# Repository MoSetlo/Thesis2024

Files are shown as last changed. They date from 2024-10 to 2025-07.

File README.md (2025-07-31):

# Thesis2024

##### Report - https://drive.google.com/drive/folders/1f2lx2jlqezw4tI6jubJ7p_Oo5HgsuzDn?usp=sharing

The purpose of this study is to design and implement a lightweight control system and remote
interface to convert a commercially available helium balloon into a fully functional blimp. This
research aims to explore how custom-designed hardware and software can transform an ordinary
inflatable structure into a maneuverable LTA vehicle, The study seeks to address key challenges
in stability, control precision, and propulsion by developing a custom motor driver, optimizing
PID-based stabilization, and minimizing latency issues using a custom-built remote controller.

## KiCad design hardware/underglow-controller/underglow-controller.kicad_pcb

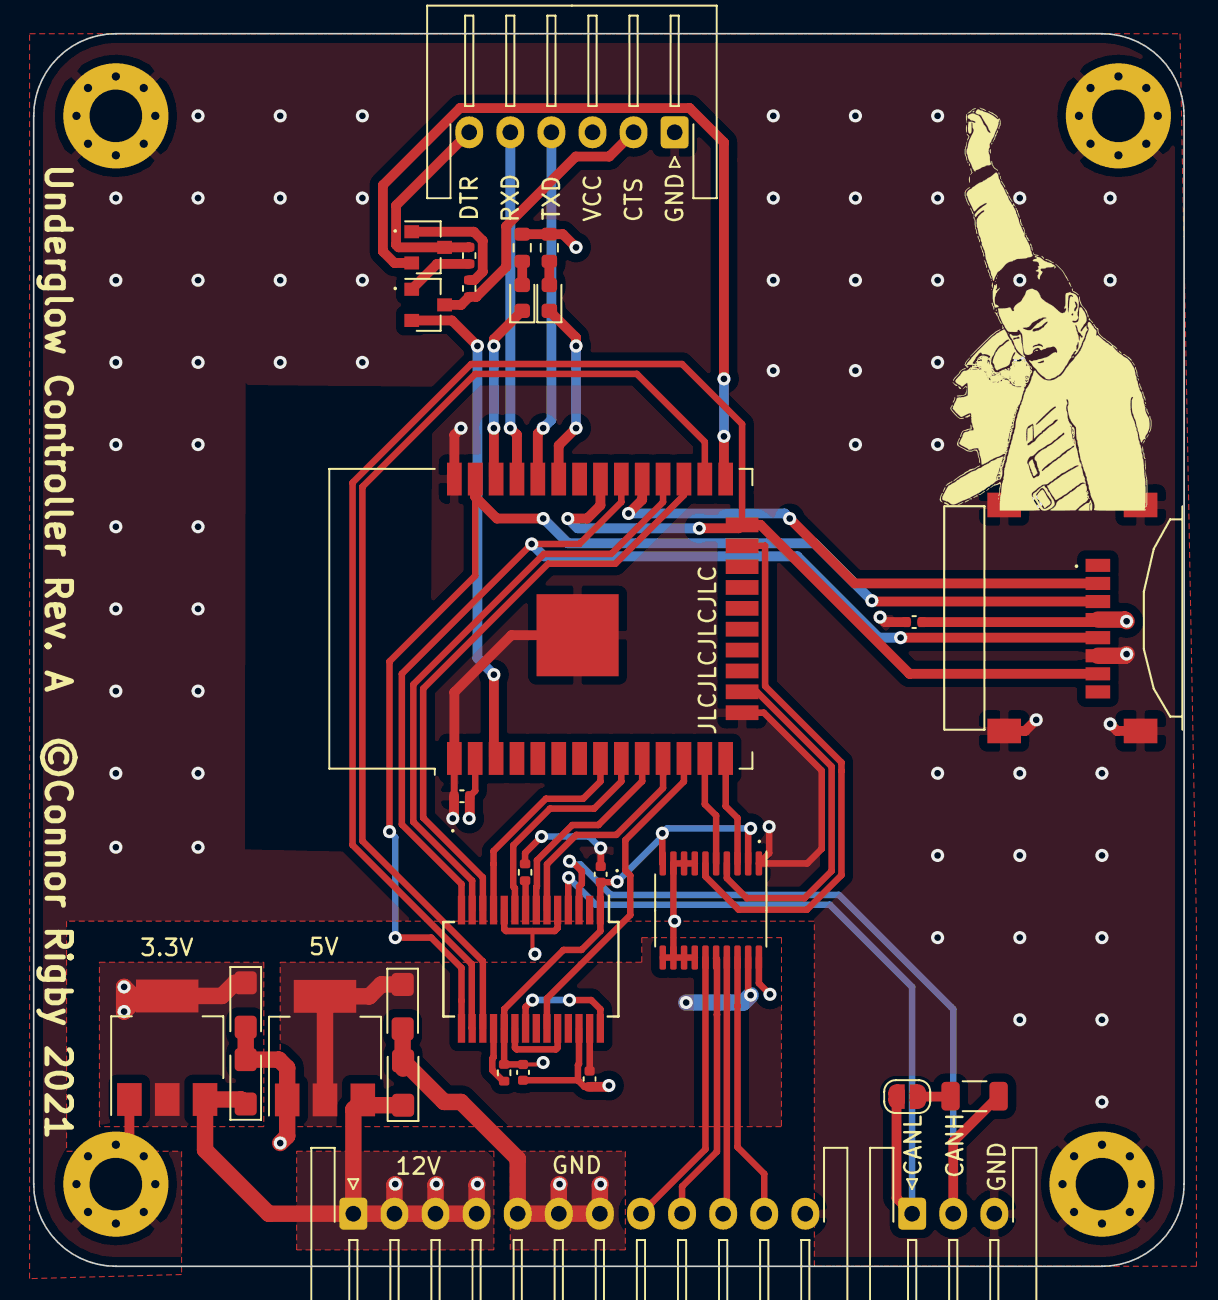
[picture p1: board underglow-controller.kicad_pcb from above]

Board: 4 copper layers, 70.0 x 75.0 mm, 34 parts (0 on the bottom side), 43 nets.

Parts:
C1, C2, C3, C4: 10u; CP_EIA-3216-18_Kemet-A
C5, C6, C7, C8, C9: 100n; C_0402_1005Metric
D1, D2: LED_Small; LED_0603_1608Metric
H1, H2, H3, H4: MountingHole_Pad; MountingHole_3.2mm_M3_Pad_Via
J1: Micro_SD_Card; MOLEX_47219-2001
J2: FTDI; JST_XH_S6B-XH-A-1_1x06_P2.50mm_Horizontal
J3: LEDS; JST_XH_S12B-XH-A-1_1x12_P2.50mm_Horizontal
J4: CAN; JST_XH_S3B-XH-A-1_1x03_P2.50mm_Horizontal
JP1: Jumper_NO_Small; SolderJumper-2_P1.3mm_Open_RoundedPad1.0x1.5mm
Q1, Q2: SS8050; SOT-23
R1, R2, R5, R6: 10k; R_0402_1005Metric
R3, R4: R_Small; R_0603_1608Metric
R7: 120; R_1206_3216Metric
U1: AMS1117-3.3; SOT-223-3_TabPin2
U2: TXS0108EPW; TSSOP-20_4.4x6.5mm_P0.65mm
U3: AMS1117-5.0; SOT-223-3_TabPin2
U4: ESP32-WROOM-32D; ESP32-WROOM-32
U5: MCP25625-x-SS; SSOP-28_5.3x10.2mm_P0.65mm

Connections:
+3V3: C2.1, C5.2, C6.2, C7.2, C8.2, J1.4, R3.1, R4.1, R5.2, U1.2, U2.2, U2.10, U4.2, U5.1, U5.19
+5V: C4.1, C9.2, U2.19, U3.2, U5.27
+12V: C1.1, C3.1, J3.1, J3.2, J3.3, J3.4, U1.3, U3.3
/CANH: J4.1, JP1.1, U5.4
/CANL: J4.2, R7.2, U5.3
/CAN_INT: U4.28, U5.13
/CAN_RX0_BF: U4.27, U5.12
/CAN_RX1_BF: U4.8, U5.11
/CAN_TX0_RTS: U4.12, U5.23
/CAN_TX1_RTS: U4.11, U5.6
/CAN_TX2_RTS: U4.10, U5.7
/FTDI_CTS: J2.2, Q1.3, R2.2
/FTDI_DTR: J2.6, Q2.3, R1.2
/FTDI_RX: J2.5, U4.35
/FTDI_TX: J2.4, U4.34
/GPIO0: Q2.2, U4.25
/LED0: U2.4, U4.16
/LED0_OUT: J3.10, U2.17
/LED1: U2.3, U4.14
/LED1_OUT: J3.11, U2.18
/LED2: U2.5, U4.13
/LED2_OUT: J3.9, U2.16
/LED3: U2.6, U4.23
/LED3_OUT: J3.8, U2.15
/RESET: Q1.2, U4.3
/SD_CLK: J1.5, U4.30, U5.14
/SD_CMD: J1.3, U4.37, U5.15
/SD_D0: J1.7, U4.24, U4.31, U5.16
/SD_D3: J1.2, U4.29
/SPI_CS: U4.26, U5.17
/STATUS0: D1.1, U4.33
/STATUS1: D2.1, U4.36
/XTAL_OUT: U4.9, U5.9
GND: C1.2, C2.2, C3.2, C4.2, C5.1, C6.1, C7.1, C8.1, C9.1, H1.1, H2.1, H3.1, H4.1, J1.6, J1.G1, J1.G2, J1.G3, J1.G4, J2.1, J3.5, J3.6, J3.7, J3.12, J4.3, R6.2, U1.1, U2.1, U2.7, U2.8, U2.9, U2.11, U2.12, U2.13, U2.14, U2.20, U3.1, U4.1, U4.15, U4.38, U4.39, U5.5, U5.10, U5.26
unnamed: D1.2, R3.2
unnamed: D2.2, R4.2
unnamed: JP1.2, R7.1
unnamed: Q1.1, R1.1
unnamed: Q2.1, R2.1
unnamed: R5.1, U5.18
unnamed: R6.1, U5.8
unnamed: U5.20, U5.24
unnamed: U5.21, U5.28

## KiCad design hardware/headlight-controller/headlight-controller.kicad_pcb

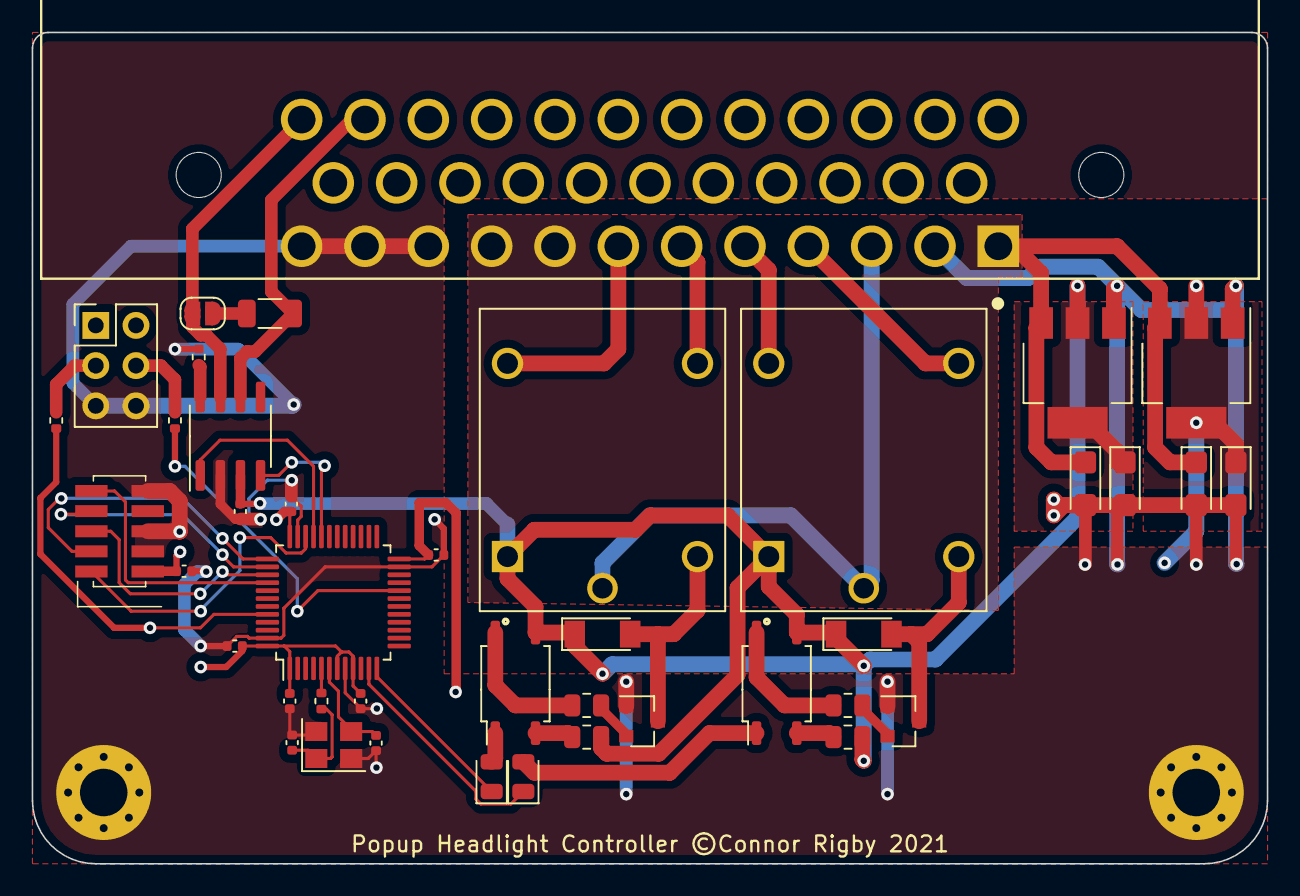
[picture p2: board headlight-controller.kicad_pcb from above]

Board: 2 copper layers, 78.0 x 52.5 mm, 43 parts (0 on the bottom side), 39 nets.

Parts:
C1, C2, C3, C7: 10u; CP_EIA-3216-18_Kemet-A
C4, C6: 12p; C_0402_1005Metric
C5, C8, C9, C10, C11, C12, C13: 100n; C_0402_1005Metric
D1, D2: RED; LED_0805_2012Metric
D3, D4: ZMM5V6; D_MiniMELF
H1, H2: MountingHole_Pad; MountingHole_3mm_Pad_Via
J1: Conn_ARM_JTAG_SWD_10; 20021221-00010C4LF
J2: 776180-1; TE_776180-1
J3: BOOT; PinHeader_2x03_P2.54mm_Vertical
JP1: Jumper_NO_Small; SolderJumper-2_P1.3mm_Open_RoundedPad1.0x1.5mm
K1, K2: SRD-05VDC-SL-C; RELAY_SRD-05VDC-SL-C
Q1, Q2: S8050; SOT-23
R1, R2: 1k; R_0805_2012Metric
R3, R4: 510; R_0805_2012Metric
R5: 120; R_1206_3216Metric
R6, R8: 100K; R_0402_1005Metric
R7: 1M; R_0402_1005Metric
R9: 4.7k; R_0402_1005Metric
U1: AMS1117-3.3; SOT-223-3_TabPin2
U2: AMS1117-5.0; SOT-223-3_TabPin2
U3: STM32F103C8Tx; LQFP-48_7x7mm_P0.5mm
U4: MCP2551-I-SN; SOIC-8_3.9x4.9mm_P1.27mm
U5, U6: EL357N(B)(TA)-G; SOP-4_4.1x4.4mm_P2.54mm
Y1: Crystal_GND24_Small; Crystal_SMD_3225-4Pin_3.2x2.5mm

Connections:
+3V3: C2.1, C5.1, C8.1, C9.1, C10.1, C11.1, C12.1, J1.1, J3.1, J3.2, U1.2, U3.1, U3.7, U3.9, U3.24, U3.36, U3.48
+5V: C7.1, C13.1, D3.1, D4.1, K1.A1, K2.A1, R1.2, R2.2, U2.2, U4.3, U5.3, U6.3
+12V: C1.1, C3.1, J2.1, J2.8, J2.9, U1.3, U2.3
/BOOT0: R6.2, U3.44
/BOOT1: R8.1, U3.20
/CANH: J2.35, JP1.1, U4.7
/CANL: J2.34, R5.1, U4.6
/CAN_RX: U3.32, U4.4
/CAN_TX: U3.33, U4.1
/HL1_DN: J2.7, K1.NC
/HL1_IN: D1.1, U3.12
/HL1_UP: J2.6, K1.NO
/HL2_DN: J2.5, K2.NC
/HL2_IN: D2.1, U3.11
/HL2_UP: J2.4, K2.NO
/HL_COM: J2.3, K1.COM, K2.COM
/HSE_IN: R7.1, U3.5
/HSE_OUT: C6.1, U3.6, Y1.3
/JNTRST: J1.10, U3.40
/SWDCLK: J1.4, U3.37
/SWDIO: J1.2, U3.34
/SWO: J1.6, U3.39
/TDI: J1.8, U3.38
GND: C1.2, C2.2, C3.2, C4.2, C5.2, C6.2, C7.2, C8.2, C9.2, C10.2, C11.2, C12.2, C13.2, H1.1, H2.1, J1.3, J1.5, J1.9, J2.2, J2.10, J2.11, J2.12, J3.5, J3.6, Q1.1, Q2.1, R9.1, U1.1, U2.1, U3.8, U3.23, U3.35, U3.47, U4.2, Y1.2, Y1.4
unnamed: C4.1, R7.2, Y1.1
unnamed: D1.2, U5.1
unnamed: D2.2, U6.1
unnamed: D3.2, K1.A2, Q1.3
unnamed: D4.2, K2.A2, Q2.3
unnamed: J3.3, R6.1
unnamed: J3.4, R8.2
unnamed: JP1.2, R5.2
unnamed: Q1.2, R3.1
unnamed: Q2.2, R4.1
unnamed: R1.1, U5.2
unnamed: R2.1, U6.2
unnamed: R3.2, U5.4
unnamed: R4.2, U6.4
unnamed: R9.2, U4.8

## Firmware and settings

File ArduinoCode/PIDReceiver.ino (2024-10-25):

#include <esp_now.h> //esp-idf
#include <WiFi.h>
#include <Adafruit_MPU6050.h>
#include <Adafruit_Sensor.h>



#define CHANNEL 6 //Must Match Slave
#define FRONT_MOTOR_PIN 12
#define BACK_MOTOR_PIN 2
#define LEFT_MOTOR_PIN 13
#define RIGHT_MOTOR_PIN 3
#define BattADCPin 5
#define FREQUENCY 40000
#define PWM_RESOLUTION 8
#define MPU_SDA 16
#define MPU_SCL 18

/** This is all the data about the peer **/
esp_now_peer_info_t slave;  //MacAdress of Receiver
uint8_t broadcastAddress[] = {0xCC,0x8D,0xA2,0x88, 0x63, 0x4A}; //CC:8D:A2:88:63:4A
esp_err_t result;



/** The all important data**/
uint8_t dataSend = 0; //Should be 250 bytes or less - can be int, struct. Struct could be useful or partition xy adc values

typedef struct joystick{ //struct to hold xy values of two joysticks from transmitter
  uint16_t xL, yL, xR, yR=500; uint8_t leftStickClick =1; 
  float Pyaw,Ppitch,Iyaw,Ipitch,Dyaw,Dpitch=0;
};
joystick joyStk;
joystick* newJoyStk = &joyStk;

typedef struct dataLog{

int_fast8_t frontMotor=0;
int_fast8_t backMotor=0;
int_fast8_t leftMotor=0;
int_fast8_t rightMotor=0;
float RateRoll, RateYaw=0;
float PitchAngle=0;
float battStatus=0;
int recLoop=0;
float Pyaw,Ppitch,Iyaw,Ipitch,Dyaw,Dpitch=0;
};

dataLog recData;


/**Global Variables**/
int_fast8_t frontMotor;
int_fast8_t backMotor;
int_fast8_t leftMotor;
int_fast8_t rightMotor;
int_fast8_t yawStick;
int_fast8_t throttleLeftStick;
int_fast8_t pitchStick;
int_fast8_t throttleRightStick; //int incase of negative signage

//BatteryVoltage============================
float battVoltage;
uint8_t batteryLow;

//IMU Gyro===================================
Adafruit_MPU6050 mpu;

float RateRoll, RatePitch, RateYaw;
float RateRollCalib, RatePitchCalib, RateYawCalib;
int RateCalibNum;
float AccelX, AccelY, AccelZ;
float AnglePitchCalib,AnglePitch=0;
int Looptimer;

//PID Terms====================================
float Pyaw,Ppitch,Iyaw,Ipitch,Dyaw,Dpitch;
float ErrorYaw,ErrorPitchRate,ErrorPitchAngle,PrevErrorYaw,PrevErrorPitchRate,PrevErrorPitchAngle,PrevItermYaw,PrevItermPitch,PrevItermPitchAngle;
float DesiredYawRate, DesiredPitchAngle;
float PIDInputYaw,PIDInputPitch=0;

float PIDReturnIterm;
//Other

uint8_t startLoop=0;



void gyro_rates()
{

/* Get new sensor events with the readings */
  sensors_event_t a, g, temp;
  mpu.getEvent(&a, &g, &temp);

  RatePitch = g.gyro.y * 57.2958;

  RateRoll = g.gyro.x * 57.2958;

  RateYaw = g.gyro.z * 57.2958;

  AccelX = a.acceleration.x/9.80665;

  AccelY = a.acceleration.y/9.80665;

  AccelZ = a.acceleration.z/9.80665;


}

float PIDcontroller(float Pconst, float Iconst, float Dconst, float Error, float PrevError, float PrevIterm,float MaxOut)
{
  float Pterm = Pconst*Error;
  float Iterm = PrevIterm + (Iconst*(Error+PrevError)*0.005/2);
  float Dterm = Dconst*(Error-PrevError)/0.005;

  //AntiWindup

  if(Iterm>MaxOut){
    Iterm=MaxOut;
  }
  else if(Iterm<-MaxOut)
  {
    Iterm=-MaxOut;
  }

  float PIDout= Pterm+Iterm+Dterm;

  if(PIDout>MaxOut){
    PIDout=MaxOut;
  }
  else if(PIDout<-MaxOut)
  {
    PIDout=-MaxOut;
  }

  //PIDReturn[0] = Error;
  PIDReturnIterm = Iterm;

  return PIDout;

}







void setup(){
//blade spin stop
  pinMode(FRONT_MOTOR_PIN, OUTPUT);  // Set as output
  digitalWrite(FRONT_MOTOR_PIN, LOW); // Ensure it's off at boot
pinMode(BACK_MOTOR_PIN, OUTPUT);  // Set as output
  digitalWrite(BACK_MOTOR_PIN, LOW); // Ensure it's off at boot
  pinMode(LEFT_MOTOR_PIN, OUTPUT);  // Set as output
  digitalWrite(LEFT_MOTOR_PIN, LOW); // Ensure it's off at boot
  pinMode(RIGHT_MOTOR_PIN, OUTPUT);  // Set as output
  digitalWrite(RIGHT_MOTOR_PIN, LOW); // Ensure it's off at boot


  /*ESPNow Setup====================================*/
  Serial.begin(115200); //Serial com
  delay(1000);
  WiFi.mode(WIFI_STA);  //Set mode to station mode
  WiFi.setChannel(CHANNEL);
  
  if (esp_now_init() != ESP_OK) { //initialises espnow protocol
    Serial.println("Error initializing ESP-NOW");
    return;
  }

  esp_now_register_send_cb(OnDataSent); //send callback on delivery
  esp_now_register_recv_cb(OnDataRecv); //send callback on reception

  memcpy(slave.peer_addr, broadcastAddress, 6); //copy broadcast address memory into slave object
  slave.channel = CHANNEL; 
  slave.encrypt =0;
  esp_now_add_peer(&slave);


  /*MPU SETUP*/
  while (!mpu.begin()) {
    Serial.println("Failed to find MPU6050 chip");
  }


  mpu.setAccelerometerRange(MPU6050_RANGE_8_G);
 
  mpu.setGyroRange(MPU6050_RANGE_500_DEG); //therefore in degrees per seconds

  mpu.setFilterBandwidth(MPU6050_BAND_10_HZ);


  pinMode(15, OUTPUT);
  digitalWrite(15, HIGH);

  delay(1000);

//beginning gyro calibration
  // digitalWrite(15, LOW);
  // delay(1000);

  // digitalWrite(15, HIGH);
  // delay(1000);

  // digitalWrite(15, LOW);


  // for(RateCalibNum =0 ; RateCalibNum<2000; RateCalibNum++)
  // {
  //   gyro_rates();
  //   RateRollCalib+=RateRoll;
  //   RatePitchCalib+=RatePitch;
  //   RateYawCalib += RateYaw;
  //   AnglePitchCalib=0.98*(AnglePitchCalib+(RatePitch*0.005)) + 0.02*(atan(-AccelX/sqrt(AccelY*AccelY + AccelZ*AccelZ)) * 57.2958);
  //   delay(1);
  // }
  
  // RateRollCalib/=2000;
  // RatePitchCalib/=2000;
  // RateYawCalib/=2000;

  // Serial.println("Calibration Complete");
  // digitalWrite(15, HIGH);
  // delay(1000);

  /*Joystick Setup===================================*/
  frontMotor,backMotor, leftMotor, rightMotor, yawStick, throttleLeftStick, pitchStick, throttleRightStick = 0;

  /*PWM SETUP===============================*/
  ledcAttach(FRONT_MOTOR_PIN, FREQUENCY, PWM_RESOLUTION);
  ledcWrite(FRONT_MOTOR_PIN, 0);

  ledcAttach(BACK_MOTOR_PIN, FREQUENCY, PWM_RESOLUTION);
  ledcWrite(BACK_MOTOR_PIN, 0);
  

  ledcAttach(LEFT_MOTOR_PIN, FREQUENCY, PWM_RESOLUTION);
  ledcWrite(LEFT_MOTOR_PIN, 0);

  ledcAttach(RIGHT_MOTOR_PIN, FREQUENCY, PWM_RESOLUTION);
  ledcWrite(RIGHT_MOTOR_PIN, 0);



  //ADC Battery Check
  analogReadResolution(10);
  batteryLow=0;

  //PID Setup variables
  PrevErrorYaw,PrevErrorPitchAngle,PrevItermYaw,PrevItermPitchAngle=0;

  Pyaw=(newJoyStk->Pyaw);
  Iyaw=(newJoyStk->Iyaw);
  Dyaw=(newJoyStk->Dyaw);

  Ppitch=(newJoyStk->Ppitch);
  Ipitch=(newJoyStk->Ipitch);
  Dpitch=(newJoyStk->Dpitch);

  //PIDReturn[0]=0;
  PIDReturnIterm=0;

  delay(3000);
  digitalWrite(15, LOW);
}

void loop(){
  //Remote control Lock 

  if(!newJoyStk->leftStickClick && newJoyStk->yR >850){
    startLoop=0; //Loop paused

    ledcWrite(FRONT_MOTOR_PIN, 0);
    ledcWrite(BACK_MOTOR_PIN, 0);
    ledcWrite(LEFT_MOTOR_PIN, 0 );
    ledcWrite(RIGHT_MOTOR_PIN, 0);

    PrevErrorYaw,PrevErrorPitchAngle,PrevItermYaw,PrevItermPitchAngle=0;
    digitalWrite(15, LOW);

    delay(3000);

  }

  while(!startLoop) //loop paused
  {

    Serial.println("Waiting for Stick Click");
    if(!newJoyStk->leftStickClick && newJoyStk->yR >550)
    {
      startLoop=1;
      digitalWrite(15, HIGH);
  
  delay(1000);

  digitalWrite(15, LOW);
  delay(1000);

  digitalWrite(15, HIGH);
  delay(1000);

  digitalWrite(15, LOW);


  for(RateCalibNum =0 ; RateCalibNum<2000; RateCalibNum++)
  {
    gyro_rates();
    RateRollCalib+=RateRoll;
    RatePitchCalib+=RatePitch;
    RateYawCalib += RateYaw;
    AnglePitchCalib=0.98*(AnglePitchCalib+(RatePitch*0.005)) + 0.02*(atan(-AccelX/sqrt(AccelY*AccelY + AccelZ*AccelZ)) * 57.2958);
    delay(1);
  }
  
  RateRollCalib/=2000;
  RatePitchCalib/=2000;
  RateYawCalib/=2000;

  Serial.println("Calibration Complete");
  digitalWrite(15, HIGH);
  delay(2000);

    }
    delay(3000);
    //calll reset errror
  }

  //Loop Timer
  Looptimer = micros();

  /*Battery Voltage Check*/
  //=============================================================
  battVoltage = (float)analogRead(BattADCPin)/205+0.3; //1024 to 5V mapp

  if(battVoltage<3.45) //assumption one would need to restart system
  {
    //batteryLow=1;
    digitalWrite(15, LOW);
    // dataSend = 1;

    // /*ESP_Now*/
    // result =  esp_now_send(slave.peer_addr, &dataSend, sizeof(dataSend)); // sends data to slave
  }
  else //assumption one would need to restart system
  {
    //batteryLow=0;
    digitalWrite(15, HIGH);
    // dataSend = 1;

    // /*ESP_Now*/
    // result =  esp_now_send(slave.peer_addr, &dataSend, sizeof(dataSend)); // sends data to slave
  }

  /*JoyStick PWM DUTY Mapping====================*/
  //====================================================
  if(newJoyStk->yL >470)  //Throttle input left joystick from joystick middle (forward propulsion) 
  {
    throttleLeftStick=0;
  }

  else if(newJoyStk->yL <=470)
  {
    throttleLeftStick = map(newJoyStk->yL, 470, 0, 0, 85); //maximum 60% speed Note int8
    
  }

  //============================================
  // Throttle input right joystick from joystick middle(lift)

  if(newJoyStk->yR>=550)
  {
    throttleRightStick=0; //10% hover
  }

  else if(newJoyStk->yR>470 && newJoyStk->xL <550)
  {
    throttleRightStick= 0; //1% hover, just to show it works
  }

  else if(newJoyStk->yR<=470)
  {
    throttleRightStick = map(newJoyStk->yR,470,0,2,125); //maximum 60% lift speed hover 
  }

  //=====================================================
  if(newJoyStk->xL <=470) //Right yaw
  {
    yawStick = map(newJoyStk->xL, 470,0,0,-150); //maximum 20% might change for no massive pwm
  }

  else if(newJoyStk->xL >=550) //Left yaw
  {
    yawStick = map(newJoyStk->xL, 550,1023,0,+150);
  }


  else if(newJoyStk->xL >470 && newJoyStk->xL <550 )
  {
    yawStick = 0;
  }

//MPU======================================
  //Looptimer = micros();
  gyro_rates();
  RateRoll-=RateRollCalib;
  RatePitch -= RatePitchCalib;
  RateYaw -= RateYawCalib;
  AnglePitch=0.98*(AnglePitch+(RatePitch*0.005)) + 0.02*((atan(-AccelX/sqrt(AccelY*AccelY + AccelZ*AccelZ)) * 57.2958)-AnglePitchCalib);

// additional
Pyaw=60
  Iyaw=9

  Ppitch=0.3
  Dpitch=5
//
  

  DesiredYawRate = 0.12*(yawStick);
  ErrorYaw= DesiredYawRate-RateYaw;

  DesiredPitchAngle=0;
  ErrorPitchAngle = DesiredPitchAngle-AnglePitch;


  PIDInputYaw = PIDcontroller(Pyaw, Iyaw, Dyaw, ErrorYaw, PrevErrorYaw, PrevItermYaw,150);
  PrevErrorYaw = ErrorYaw;
  PrevItermYaw = PIDReturnIterm;


  PIDInputPitch = PIDcontroller(Ppitch, Ipitch, Dpitch, ErrorPitchAngle, PrevErrorPitchAngle, PrevItermPitchAngle, 50);
  PrevErrorPitchAngle = ErrorPitchAngle;
  PrevItermPitchAngle = PIDReturnIterm;


  leftMotor = throttleLeftStick - PIDInputYaw;
  rightMotor = throttleLeftStick + PIDInputYaw;
  frontMotor = throttleRightStick - PIDInputPitch;
  backMotor = throttleRightStick + PIDInputPitch;

  if(leftMotor<0)
  {
    leftMotor=0;
  }
  if(rightMotor<0)
  {
    rightMotor=0;
  }
  if(frontMotor<0)
  {
    frontMotor=0;
  }
  if(backMotor<0)
  {
    backMotor=0;
  }

  if(leftMotor>250)
  {
    leftMotor=250;
  }
  if(rightMotor>250)
  {
    rightMotor=250;
  }
  if(frontMotor>250)
  {
    frontMotor=250;
  }
  if(backMotor>250)
  {
    backMotor=250;
  }




  ledcWrite(FRONT_MOTOR_PIN, frontMotor);
  ledcWrite(BACK_MOTOR_PIN, backMotor);
  ledcWrite(LEFT_MOTOR_PIN, leftMotor );
  ledcWrite(RIGHT_MOTOR_PIN, rightMotor);

  recData.frontMotor = frontMotor;
  recData.backMotor = backMotor;
  recData.leftMotor = leftMotor;
  recData.rightMotor = rightMotor;
  recData.PitchAngle = AnglePitch;
  recData.RateYaw = RateYaw;
  recData.RateRoll = RateRoll;
  recData.battStatus = battVoltage;
  recData.recLoop = micros()-Looptimer;
  recData.Ppitch = Ppitch;
  recData.Pyaw = Pyaw;
  recData.Ipitch = Ipitch;
  recData.Iyaw = Iyaw;
  recData.Dpitch = Dpitch;
  recData.Dyaw = Dyaw;
  

  result =  esp_now_send(slave.peer_addr, (uint8_t*)&recData, sizeof(recData)); // sends data to slave


  


  //Serial.printf("%d \t %d \t %.2f \t %d \t %d \t %.2f \t %.2f \t %d \t %.2f\n", frontMotor,backMotor,AnglePitch,leftMotor, rightMotor,RateYaw, RateRoll, micros()-Looptimer ,battVoltage);
  while(micros()-Looptimer < 5000);
  

}


void OnDataSent(const uint8_t *mac_addr, esp_now_send_status_t status) //callback, expectation for 0 output
{
  // Serial.print("Data status ->");
  // Serial.println(status);
}

void OnDataRecv(const esp_now_recv_info_t * esp_now_info, const uint8_t *data, int data_len) //callback on reception
{
  newJoyStk = (joystick*) data;
  // Serial.print("Data received by ->");
  // Serial.println(*data);
  // memcpy(&newData, data, sizeof(newData));

}

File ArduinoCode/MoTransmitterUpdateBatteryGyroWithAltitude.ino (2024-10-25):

#include <esp_now.h> //esp-idf
#include <WiFi.h>
#include <esp_timer.h>

#define CHANNEL 6 //Must Match Slave
#define X_Left 5
#define Y_Left 3
#define X_Right 9
#define Y_Right 7
#define altitudeHoldBtn 12



/** This is all the data about the peer **/
esp_now_peer_info_t slave;  //MacAdress of Receiver
uint8_t broadcastAddress[] = {0xCC,0x8D,0xA2,0x8B, 0xFF, 0x7A};
esp_err_t result;



/** The all important data! **/
//uint8_t data = 0; //Should be 250 bytes or less - can be int, struct. Struct could be useful or partition xy adc values
typedef struct joystick{ //struct to hold xy values of two joysticks
  uint16_t xL, yL, xR, yR=500; uint8_t leftStickClick=1; 
  float Pyaw,Ppitch,Iyaw,Ipitch,Dyaw,Dpitch=0;
};
joystick joyStk;

typedef struct dataLog{

int_fast8_t frontMotor=0;
int_fast8_t backMotor=0;
int_fast8_t leftMotor=0;
int_fast8_t rightMotor=0;
float RateRoll, RateYaw=0;
float PitchAngle=0;
float battStatus=4;
int recLoop=0;
float Pyaw,Ppitch,Iyaw,Ipitch,Dyaw,Dpitch=0;

};

dataLog recData;
dataLog *newRecData = &recData;


uint8_t startLoop=0;

//dataReceice
uint8_t dataReceive=0;


/**Packet timer rate**/
uint_fast8_t counter=0;
uint_fast64_t start=0;
uint_fast64_t end = 0;

//Others
String PIDsym;
float PIDval;
int LoopTimer=0;

//ExternalInterrupt
uint8_t altHoldStatus=0;
int_fast8_t externalCounter=0;
int_fast8_t altHoldVal=512;
uint32_t debounceTimer=0;


// void IRAM_ATTR altitudeHold()
// {

  
//   if(!altHoldStatus)
//   {
//     altHoldStatus=1;
//     altHoldVal= analogRead(X_Right); 
//     digitalWrite(39,HIGH);
//     externalCounter=0;
//   }
//   else if(altHoldStatus && altHoldVal>470)
//   {
//     altHoldStatus=0;
//     digitalWrite(39,LOW);

//   }



//}

void setup(){
  /*ESP_Now setup*/
  Serial.begin(115200); //Serial com
  delay(1000);
  WiFi.mode(WIFI_STA);  //Set mode to station mode
  WiFi.setChannel(CHANNEL);

  if (esp_now_init() != ESP_OK) { //initialises espnow protocol
    Serial.println("Error initializing ESP-NOW");
    return;
}

  esp_now_register_send_cb(OnDataSent); //send callback on delivery
  esp_now_register_recv_cb(OnDataRecv); //send callback on reception


  memcpy(slave.peer_addr, broadcastAddress, 6); //copy broadcast address memory into slave object
  slave.channel = CHANNEL; 
  slave.encrypt =0;
  esp_now_add_peer(&slave);
  

  /*Joystick Module Setup*/
  analogReadResolution(10); //10 bit resolution
  pinMode(11,INPUT_PULLUP);
  pinMode(12, INPUT_PULLUP);

  //attachInterrupt(altitudeHoldBtn, altitudeHold, FALLING);
  
  /*Digital LED Pin 15 setup*/
  pinMode(15,OUTPUT);
  digitalWrite(15,HIGH);

  pinMode(39, OUTPUT);
  digitalWrite(39, LOW);
  
}

void loop(){ 
if(Serial.available()>0)
{
  PIDsym = Serial.readString();
  while(Serial.available()==0){Serial.println("Waiting float");}

  PIDval = Serial.parseFloat();


  if(PIDsym.equalsIgnoreCase("PP"))
  {
    joyStk.Ppitch = PIDval;
  }
  else if(PIDsym.equalsIgnoreCase("IP"))
  {
    joyStk.Ipitch = PIDval;
  }
  else if(PIDsym.equalsIgnoreCase("DP"))
  {
    joyStk.Dpitch = PIDval;
  }
  else if(PIDsym.equalsIgnoreCase("PY"))
  {
    joyStk.Pyaw = PIDval;
  }
  else if(PIDsym.equalsIgnoreCase("IY"))
  {
    joyStk.Iyaw = PIDval;
  }
  else if(PIDsym.equalsIgnoreCase("DY"))
  {
    joyStk.Dyaw = PIDval;
  }



}

if(!digitalRead(altitudeHoldBtn) && (micros()-debounceTimer)>200000)
{
  
  if(!altHoldStatus)
  {
    altHoldStatus=1;
    altHoldVal= analogRead(X_Right); 
    digitalWrite(39,HIGH);
    externalCounter=0;
  }
  else if(altHoldStatus && altHoldVal>470)
  {
    altHoldStatus=0;
    digitalWrite(39,LOW);

  }

  debounceTimer=micros();
}

LoopTimer = micros();

  /*Joystick Module Loop*/
  

  joyStk.yL = analogRead(X_Left); joyStk.xL= analogRead(Y_Left); joyStk.xR = analogRead(Y_Right), joyStk.leftStickClick = digitalRead(11) ; joyStk.yR = analogRead(X_Right);  //Read of all joysticks

  if(altHoldStatus)
  {
    externalCounter++;

    if(externalCounter==100){digitalWrite(39,HIGH);}

    else if (externalCounter==200){
    
    externalCounter=0;
      

    if(joyStk.yR <470 && joyStk.yR>150)
    {
      altHoldVal-=5;
      digitalWrite(39,LOW);

    }
    else if(joyStk.yR <=150) //20 seconds to max power of 150
    {
      altHoldVal-=25;
      digitalWrite(39,LOW);
    }
    else if(joyStk.yR >550 && joyStk.yR <870)
    {
      altHoldVal+=5;
      digitalWrite(39,LOW);
    }
    else if(joyStk.yR >=870) //20 seconds to max power of 150
    {
      altHoldVal+=25;
      digitalWrite(39,LOW);
    }
    }


    if(altHoldVal<0)
    {
      altHoldVal=0;
    }
    else if(altHoldVal>1000)
    {
      altHoldVal=1000;
    }
    joyStk.yR = altHoldVal;



  }
  else
  {
    joyStk.yR = analogRead(X_Right); 
  }

  // while(digitalRead(11) && !startLoop )
  // {
  //   Serial.println("Waiting for Start");
  // }

  //startLoop=1;

  /*Battery Low Voltage Tranmission*/
  if(newRecData->battStatus<3.45)
  {
    digitalWrite(15, LOW);
  }
  else
  {
    digitalWrite(15, HIGH);
  }

  /*ESP_Now Loop*/
  result =  esp_now_send(slave.peer_addr, (uint8_t*)&joyStk, sizeof(joystick)); // sends data to slave

  if(result == ESP_OK && counter==50)
  {
    start = esp_timer_get_time();
  }

  if(result == ESP_OK)
  {
    counter++;
  }


  if(result == ESP_OK && counter==250)
  {
    counter=0;
    end = esp_timer_get_time();
    //Serial.printf("%llu\n",(end - start)/1000);
    

  }

  Serial.printf("%d \t, %d \t, %.2f \t, %d \t, %d \t, %.2f \t, %.2f \t, %d \t, %.2f\t, %.3f\t, %.3f\t, %.3f\t, %.3f\t, %.3f\t, %.3f\t,", newRecData->frontMotor/*altHoldStatus*/,newRecData->backMotor/*altHoldVal*/,newRecData->PitchAngle,newRecData->leftMotor, newRecData->rightMotor,newRecData->RateYaw,newRecData-> RateRoll,newRecData->recLoop,
  newRecData->battStatus,newRecData->Ppitch, newRecData->Ipitch,newRecData->Dpitch,newRecData->Pyaw, newRecData->Iyaw, newRecData->Dyaw );

  Serial.println(micros()-LoopTimer);
  


  //delay(3000);
  // data++;
}

void OnDataSent(const uint8_t *mac_addr, esp_now_send_status_t status) //callback, expectation for 0 output
{
  // Serial.print("Data status ->");
  // Serial.println(status);
}

void OnDataRecv(const esp_now_recv_info_t * esp_now_info, const uint8_t *data, int data_len) //callback on reception
{
  //dataReceive = *data;

  newRecData = (dataLog*)data;
  // Serial.print("Data received by ->");
  // Serial.println(*data);
  // memcpy(&newData, data, sizeof(newData));

}

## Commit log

2024-10-25 Upload of Arduino Files
2024-10-25 Add Kicad Schematic Files
    [RCXwing.kicad_sch, XwingRC.kicad_pcb, XwingRC.kicad_sch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]
2024-10-25 Added LTspice Motor Driver Simulation Schematic
